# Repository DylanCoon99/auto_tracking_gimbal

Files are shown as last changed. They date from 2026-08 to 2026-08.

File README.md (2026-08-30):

# Gimbal

A 2-axis object tracking gimbal powered by a Raspberry Pi 5. The system uses a Pi camera and OpenCV's CSRT correlation tracker to follow a user-selected target in real time, adjusting pan and tilt servos via proportional error feedback.

## Mechanical Design

The gimbal housing was designed in Fusion 360 and 3D printed.

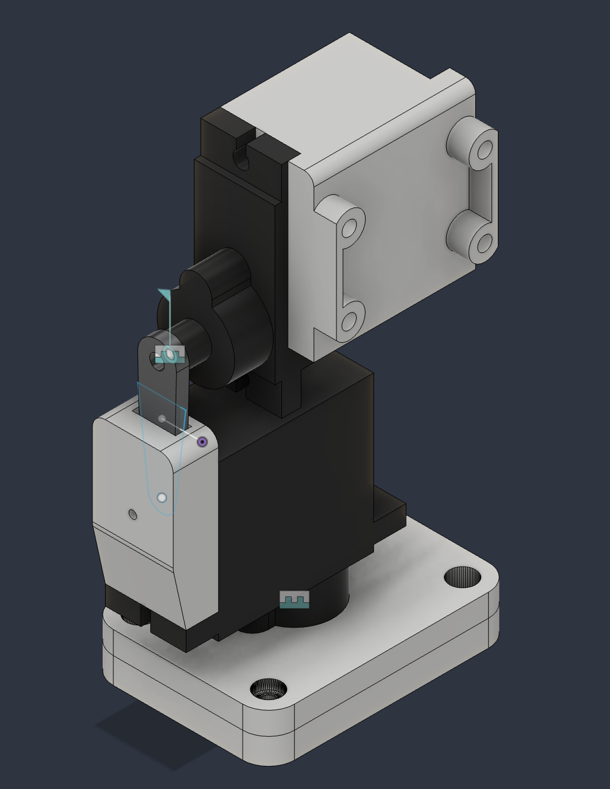
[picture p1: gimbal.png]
Gimbal


## Hardware

- Raspberry Pi 5
- Raspberry Pi Camera Module (ribbon cable)
- PCA9685 16-channel PWM/servo driver board (I2C, default address `0x40`)
- 2x hobby servos (pan and tilt)

## Software Overview

| File | Description |
|---|---|
| `src/__main__.py` | Entry point |
| `src/config.py` | `GimbalConfig` context manager: camera setup, tracking loop, error computation, servo updates |
| `src/servo.py` | Servo hardware interface: setup, position updates, reset |
| `deploy.sh` | Deploys code to the Pi over SSH and runs it |

### How It Works

1. The camera captures a frame and the user selects a region of interest (ROI)
2. On each subsequent frame, the CSRT tracker locates the object
3. Normalized error is computed as the offset of the bounding box center from the frame center, scaled to [-1, 1]
4. Proportional gain (`kp`) converts the error into a servo angle adjustment
5. Servos are updated to recenter the object in the frame

## Setup

### Raspberry Pi

1. Install system dependencies:

```bash
sudo apt-get install -y swig liblgpio-dev
```

2. Create a virtual environment with access to system packages (required for `picamera2`):

```bash
python3 -m venv --system-site-packages .venv
```

3. Install Python dependencies:

```bash
.venv/bin/pip install -r src/requirements.txt
```

### Development Machine (macOS)

1. Install [XQuartz](https://www.xquartz.org/) for X11 forwarding (required to display the tracking window over SSH):

```bash
brew install --cask xquartz
```

Log out and back in after installing.

2. Ensure you have SSH key access to the Pi.

## Deployment

The `deploy.sh` script syncs the project to the Pi and runs it:

```bash
./deploy.sh
```

This will:
- Rsync the project files to the Pi
- Install dependencies
- Launch the tracking application with X11 forwarding

## Usage

1. Run `./deploy.sh` from the development machine
2. A camera preview window will appear. Select the object to track by drawing a bounding box, then press SPACE or ENTER
3. The gimbal will follow the selected object. Press `q` to quit

## Configuration

`GimbalConfig` accepts the following parameters:

| Parameter | Default | Description |
|---|---|---|
| `channels` | `16` | Number of PCA9685 channels |
| `address` | `0x40` | I2C address of the PCA9685 board |
| `size` | `(640, 480)` | Camera resolution |
| `kp` | `10` | Proportional gain |
| `kd` | `0` | Derivative gain (not yet implemented) |

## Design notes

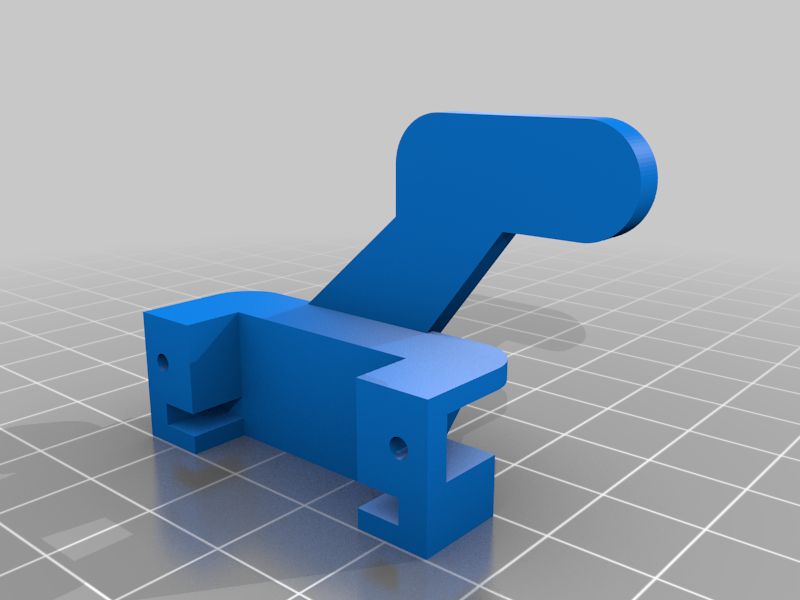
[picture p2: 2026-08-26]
images/add75e77a8224981e14c622e23811bcf.png

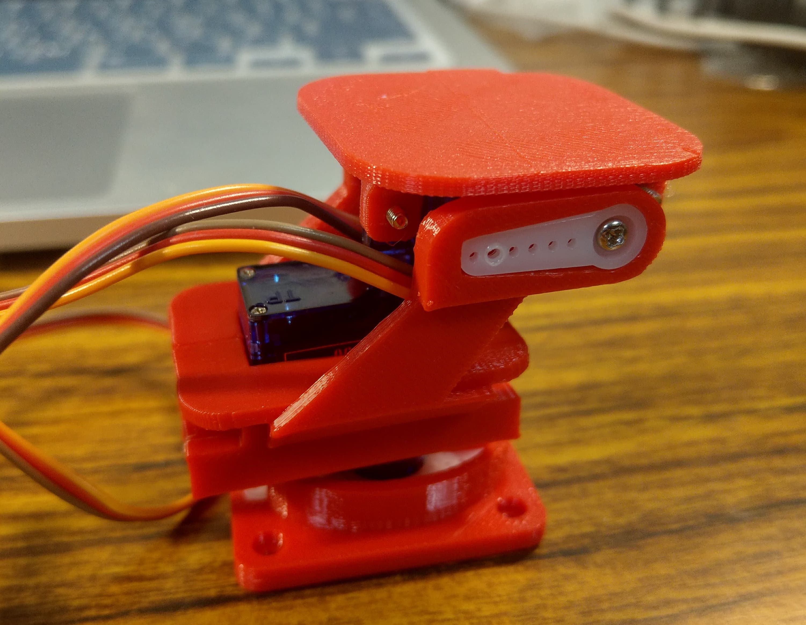
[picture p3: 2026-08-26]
images/31880622_2032063286807135_2700534414768603136_n.jpg

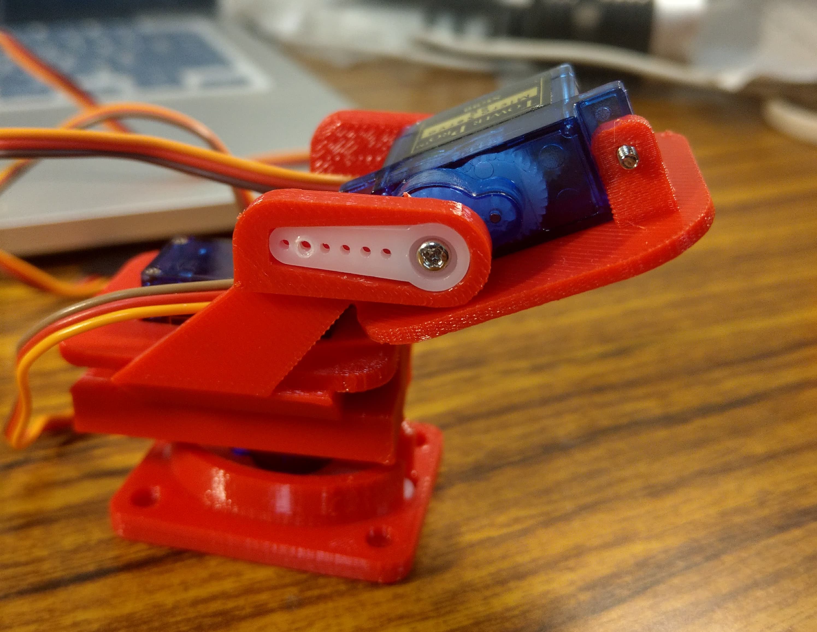
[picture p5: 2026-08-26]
images/31945504_2032062926807171_4725360110396768256_n.jpg

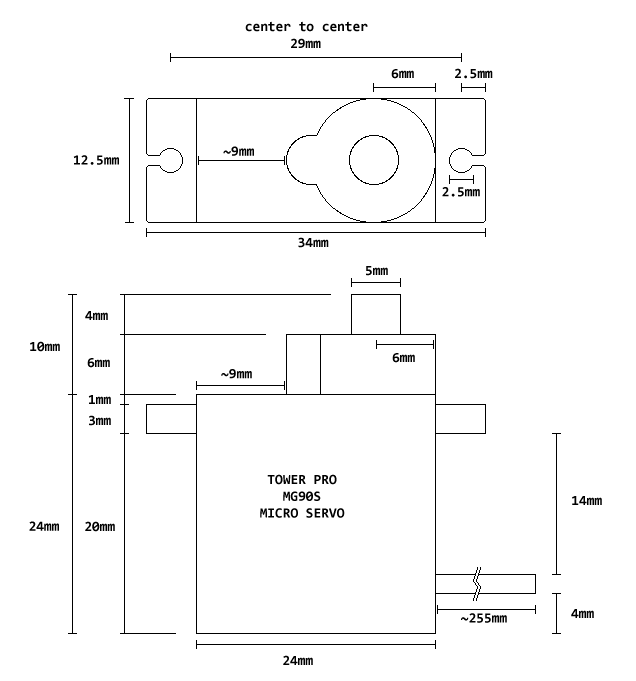
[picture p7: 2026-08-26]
r1qksoc9in611.gif

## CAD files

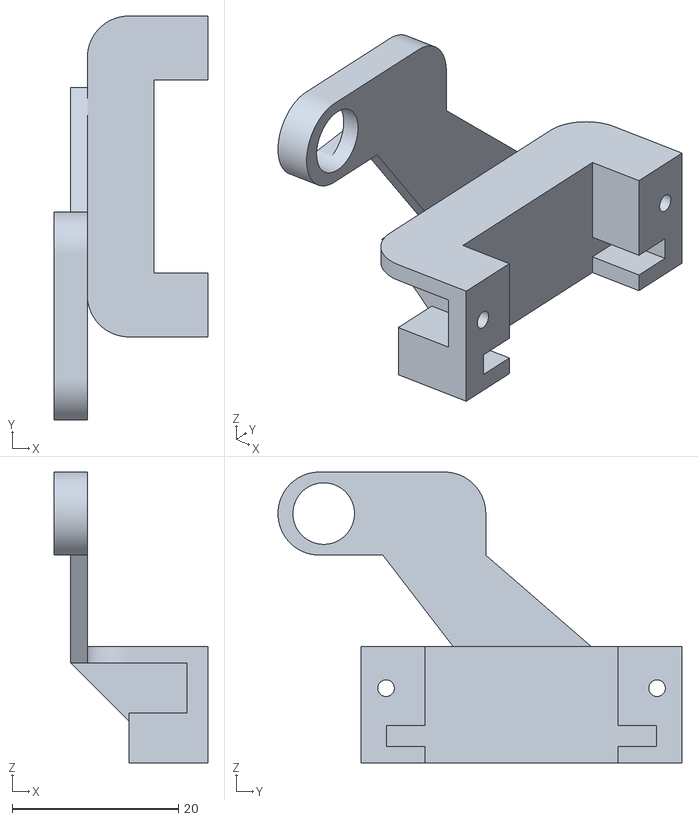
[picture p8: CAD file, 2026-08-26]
files/HolderR.stl
18.5 x 48.6 x 35.0

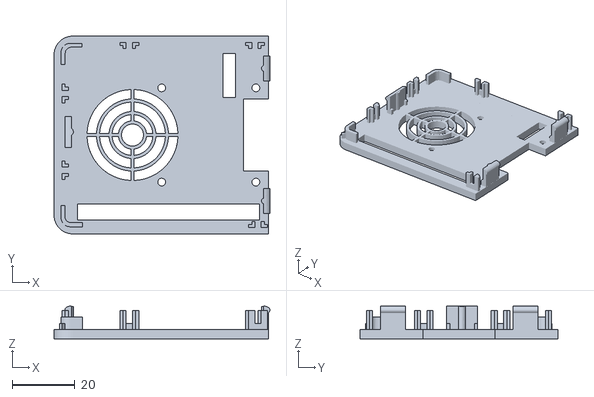
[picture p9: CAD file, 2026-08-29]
my_design/stls/Case_Lid_with_holes.stl
68.8 x 63.0 x 10.5

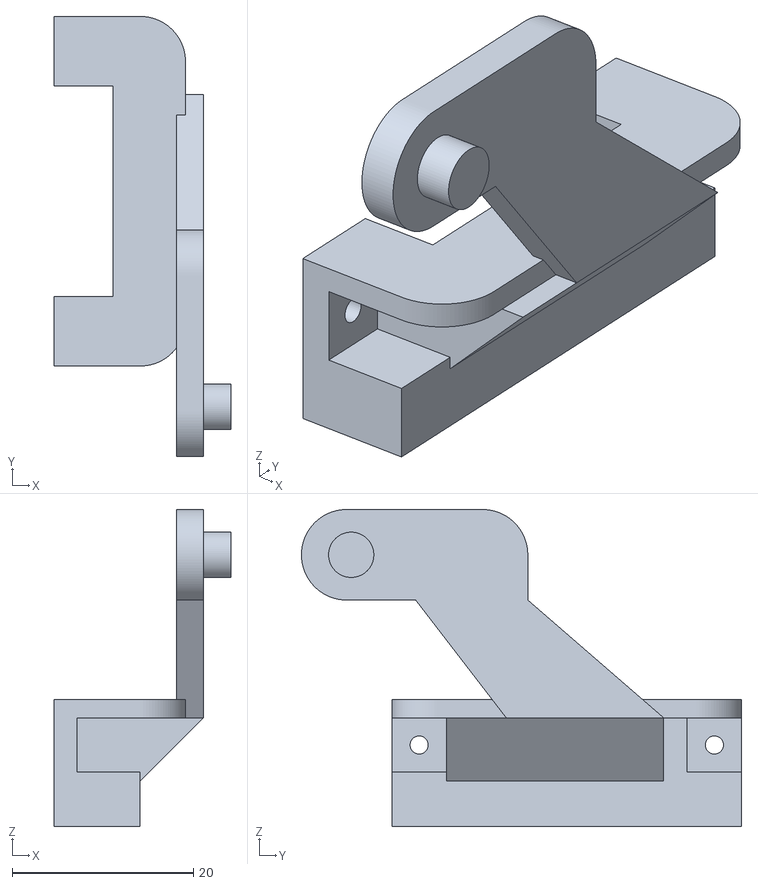
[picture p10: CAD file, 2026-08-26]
files/HolderL.stl
19.5 x 48.6 x 35.0

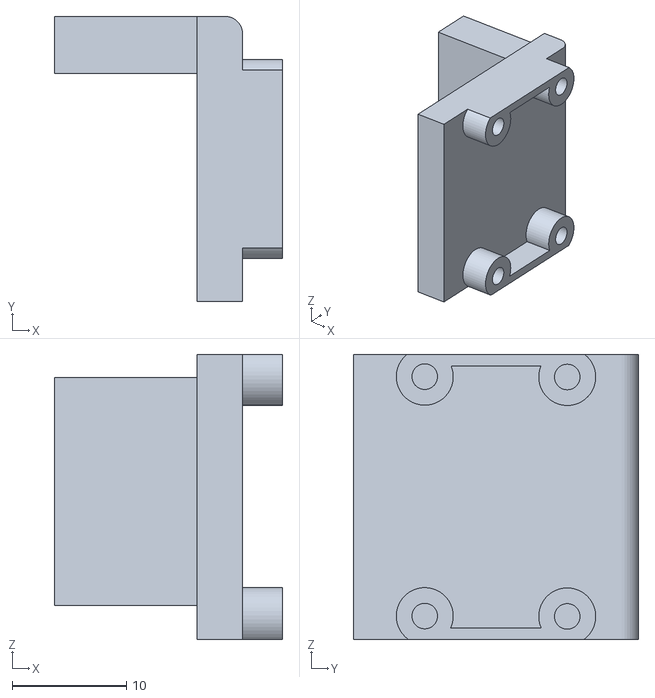
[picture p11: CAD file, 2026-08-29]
my_design/stls/camera mount.stl
20.0 x 25.0 x 25.0

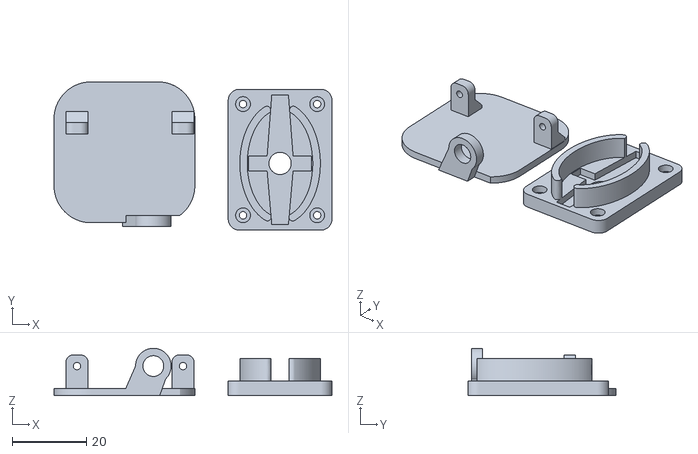
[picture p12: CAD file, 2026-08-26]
files/base.stl
75.0 x 40.0 x 12.8

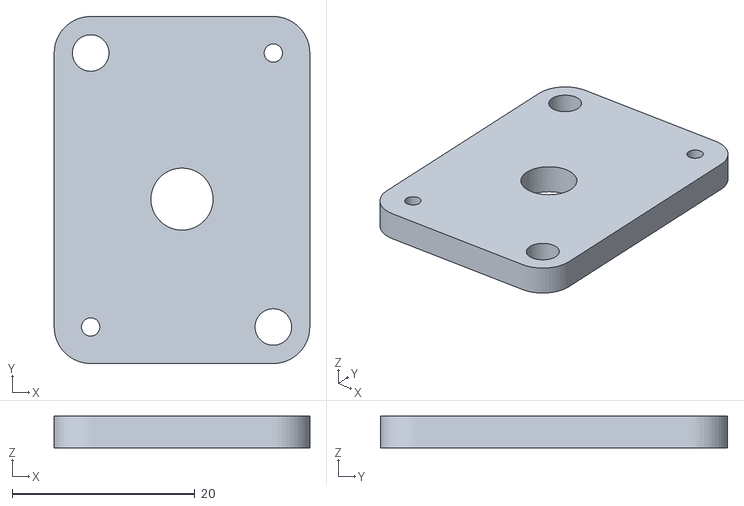
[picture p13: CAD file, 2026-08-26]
my_design/stls/top base plate.stl
28.0 x 38.0 x 3.50

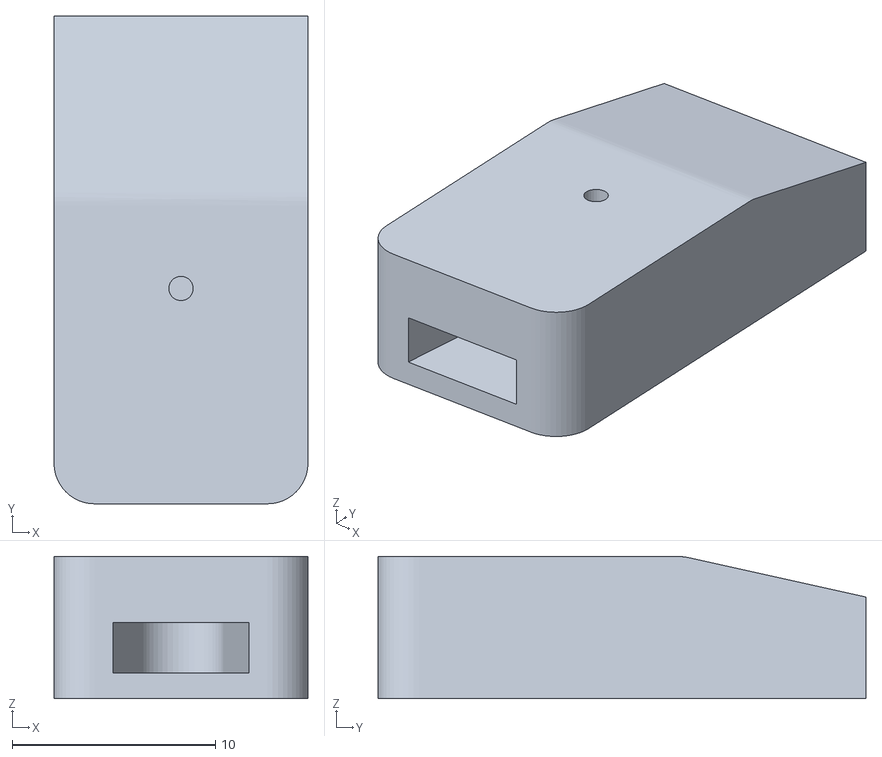
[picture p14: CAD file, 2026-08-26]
my_design/stls/Tilt Servo Mount.stl
12.5 x 24.0 x 7.00

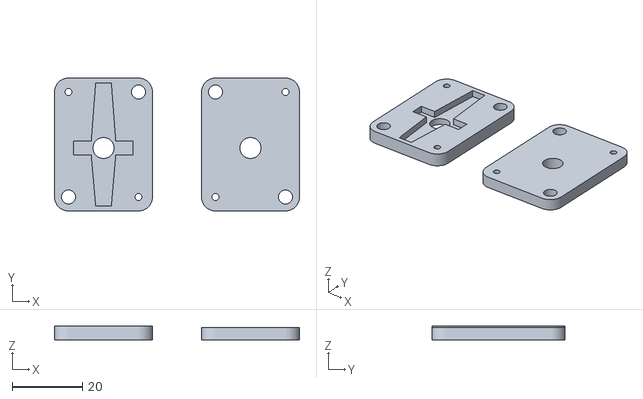
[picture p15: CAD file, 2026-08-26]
my_design/stls/Base Plate.stl
70.0 x 38.0 x 4.00

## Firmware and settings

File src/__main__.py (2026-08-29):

#from src.testing import main
from src.config import GimbalConfig




# instantiate a logger






def main():


	with GimbalConfig() as gc:
		gc.run()



	# instantiate the tracking loop

	# on each iteration

		# get the next bbox

		# measure the error for the current state of the gimbal

		# move the gimbal to the next state


	return






if __name__ == "__main__":
    main()

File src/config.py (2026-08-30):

# create a data class that stores the state of our gimbal
import logging
import time
import cv2
from libcamera import Transform
from picamera2 import Picamera2
from src.servo import servo_kit_setup, update_servos, reset



'''

Attributes
	tracker
	pi camera
	servo kit
	logger


Methods
	__init__
	__enter__
	__exit__
	current_frame
	get_next_frame
	error (gets the error for the current frame)
	update_servos


make it a context manager class: when in closes clear the window, exit and set the servos to origin



'''


class GimbalConfig:
	def __init__(self, channels=16, address=0x40, size=(640, 480), kp=10, kd=0):
		"""Initialize parameters needed for setup."""
		self.channels = channels
		self.address = address
		self.size = size
		self.logger = logging.getLogger(__name__)
		self.tracker = None
		self.picam2 = None
		self.servo_kit = None
		self.current_frame = None
		self.kp = kp
		self.kd = kd

		# Configures the root logger globally
		logging.basicConfig(
			level=logging.INFO,
			format="%(asctime)s - %(levelname)s - %(message)s",
			handlers=[logging.StreamHandler()]
		)

		self.logger.info("Initializing GimbalConfig with parameters")
		self.logger.info(f"channels: {self.channels}")
		self.logger.info(f"address: {self.address}")
		self.logger.info(f"size: {self.size}")



	def __enter__(self):
		"""Set up the resource and return the target variable."""

		self.servo_kit = servo_kit_setup(self.channels, self.address)
		reset(self.servo_kit)

		self.tracker = cv2.TrackerCSRT_create()

		# Initialize Pi camera
		self.picam2 = Picamera2()
		self.picam2.configure(self.picam2.create_preview_configuration(main={"format": "RGB888", "size": self.size}, transform=Transform(hflip=True, vflip=True)))
		self.picam2.start()
		time.sleep(2)  # let camera auto-exposure settle

		# Read the very first frame
		self.current_frame = self.picam2.capture_array()
		if self.current_frame is None:
			self.logger.error("Failed to read video")
			exit()

		# Manually select the bounding box (ROI) on the first frame
		# Press ENTER or SPACE after selecting the box
		bbox = cv2.selectROI("Tracking Window", self.current_frame, fromCenter=False, showCrosshair=True)

		# Initialize the tracker with the selected bounding box
		self.tracker.init(self.current_frame, bbox)

		

		return self


	def run(self):

		while True:
			frame = self.picam2.capture_array()
			self.current_frame = frame
			if frame is None:
				break

			# Update the tracker with the new frame
			success, bbox = self.tracker.update(frame)

			# If the object is tracked successfully, draw the rectangle
			if success:
				x, y, w, h = [int(v) for v in bbox]
				error = self._get_error(bbox)
				self.logger.info(f"BBOX ERROR: {error}")
				self._update_servo_state(error)
				cv2.rectangle(frame, (x, y), (x + w, y + h), (0, 255, 0), 2)
				cv2.putText(frame, "Tracking", (75, 75), cv2.FONT_HERSHEY_SIMPLEX, 0.7, (0, 255, 0), 2)
			else:
				cv2.putText(frame, "Lost", (75, 75), cv2.FONT_HERSHEY_SIMPLEX, 0.7, (0, 0, 255), 2)
			
			# Display the output
			cv2.imshow("Tracking Window", frame)

			# Exit loop if 'q' key is pressed
			if cv2.waitKey(1) & 0xFF == ord('q'):
				break

		return

	def _get_error(self, bbox):
		# gets the error of the current frame
		x, y, w, h = [int(v) for v in bbox]

		frame_center = (self.size[0] / 2, self.size[1] / 2)
		bbox_center = (x + w/2, y + h/2)

		error_x = (bbox_center[0] - frame_center[0]) / (self.size[0] / 2)
		error_y = (bbox_center[1] - frame_center[1]) / (self.size[1] / 2)

		return (error_x, error_y)


	def _update_servo_state(self, error):
		# interfaces with the servo kit (servo.py)
		# updates the servo state

		self.logger.info("Updating servos")
		update_servos(self.servo_kit, error, self.kp, self.kd)

		return

	def __exit__(self, exc_type, exc_val, exc_tb):
		"""Clean up the resource, regardless of errors."""
		self.logger.info("Exiting GimbalConfig")
		self.picam2.stop()
		cv2.destroyAllWindows()
		reset(self.servo_kit)

		if exc_type is not None:
			self.logger.error(f"An error occurred: {exc_val}")
			return False

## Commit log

2026-08-26 restructured directory
    [Base Plate.stl, Tilt Servo Mount.stl, top base plate.stl]
2026-08-26 servo test
2026-08-29 servo test script
    [Case_Lid_with_holes.stl, camera mount.stl]
2026-08-30 basic loop working with proportional error control
    [config.py]
